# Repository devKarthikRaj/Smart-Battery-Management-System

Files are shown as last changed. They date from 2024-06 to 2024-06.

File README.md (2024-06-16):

# NTU EE3180 Design Innovation Project 3S Battery Management System (BMS) AY2023-24
> [!IMPORTANT]
> This was a group project. The parts of the project I worked on are in this repo.

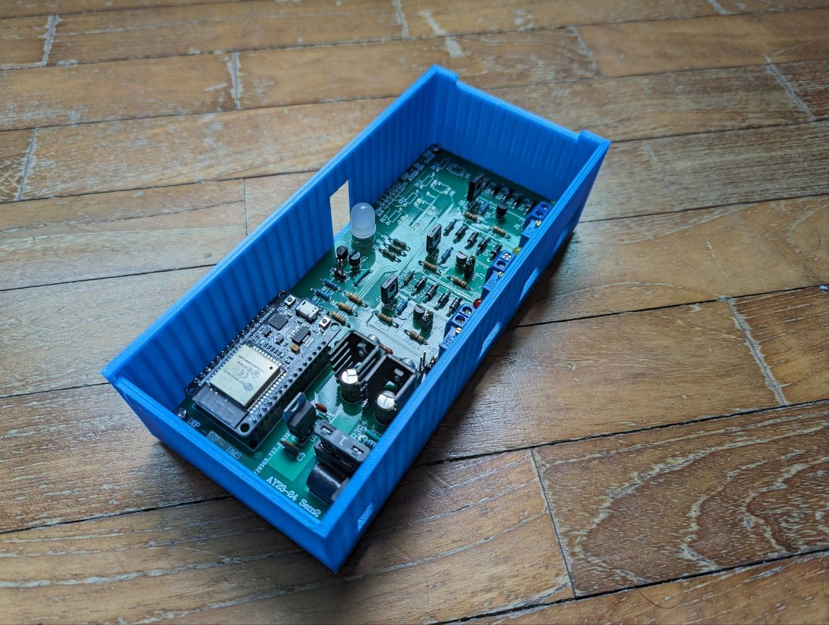
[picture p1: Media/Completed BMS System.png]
<br>

## About
With the advent of electric vehicles, charging has become an integral part of our daily lives. This has resulted in a sudden increase in the demand for battery chargers, specifically lithium-ion battery chargers. These lithium-ion batteries are very needy. They have to be charged at a specific voltage and current to remain healthy and function reliably. When charging multiple lithium-ion cells in a battery pack, they have to be charged and discharged in a balanced manner. Over-charging or over-discharging a particular cell in a battery pack could lead to dire consequences i.e the battery going BOOM!!! Now we certainly do not want that. This is where our battery management system (BMS) comes in. 

This BMS we created balance charges 3 lithium-ion cells, basically a glorified lithium-ion battery charger. Why glorified? Well, most chargers / passive BMS on the market right now just charge batteries. There is no monitoring capability whatsoever. Due to this, we cannot leave our batteries unattended while charging them. What if I want to do a grocery run while I charge my batteries? What if I want to go for an evening run while I charge my batteries? I can't do any of those things. This is where our BMS comes in! Our BMS lets you monitor your batteries while they are charging from anywhere in the world through a webpage and a mobile app available on both iOS and Android devices. 

## Contents
The parts of the project I worked on are the BMS PCB designed in Altium Designer, a part of the ESP32 firmware written in C++ through the Arduino IDE and an enclosure for the PCB designed in Fusion 360 and 3D printed with TPU.

## BMS PCB
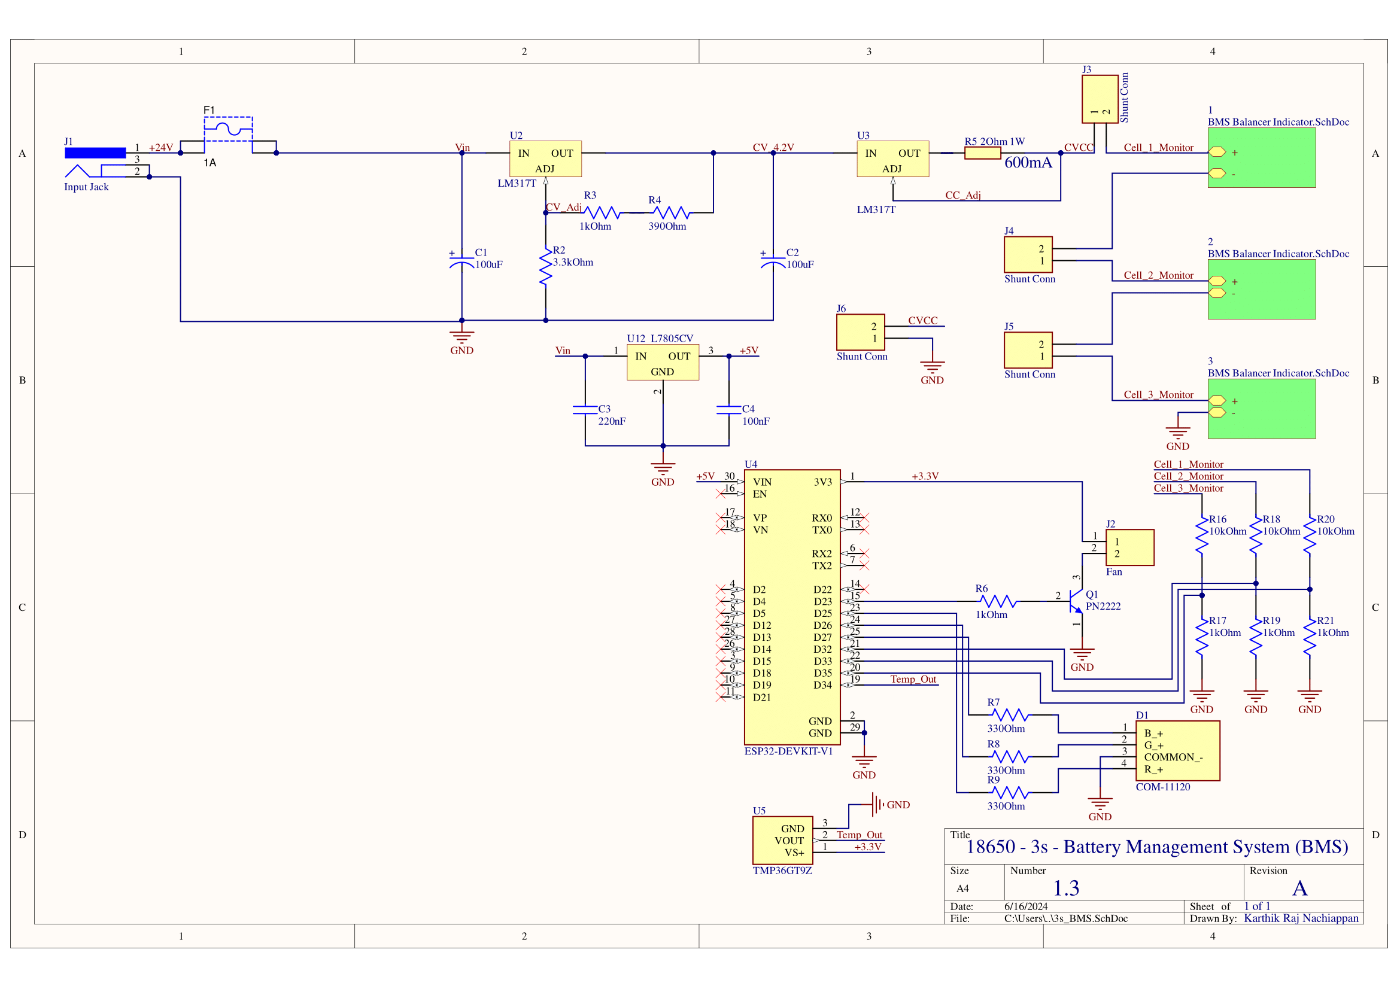
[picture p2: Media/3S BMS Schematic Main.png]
<br>
This is the main schematic. The top half of the schematic is the constant voltage constant current CV/CC circuit implemented using an adjustable LM317 voltage regulator. The bottom half of the schematic is the ESP32 microcontroller board to sensor/actuator interface circuit - This circuit connects the onboard temperature sensor, RGB LED and mini fan to the the microcontroller. This circuit also connects various parts of the charging circuit to the ESP32 to allow the microcontroller to non-invasively monitor the charging process.

&nbsp;

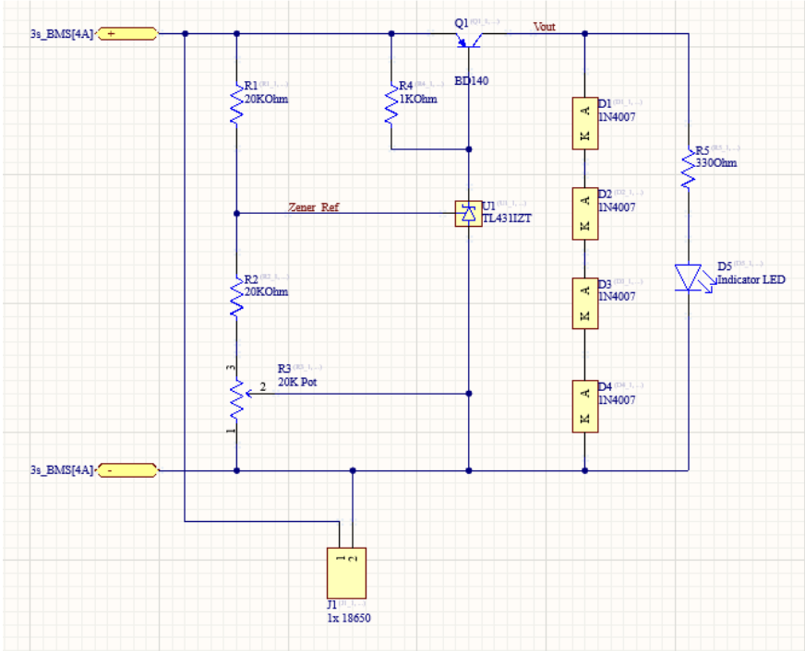
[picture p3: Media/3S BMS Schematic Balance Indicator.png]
<br>
This circuit is contained inside the green circuit blocks in the main schematic. This particular circuit is in charge of cutting off the charging process when the max desired cell voltage has been reached. This max desired cell voltage can be set by adjusting the potentiometer. Once the max desired cell voltage is reached, the indicator LED will light up giving a visual indicator to the user that the charging process is complete.

&nbsp;

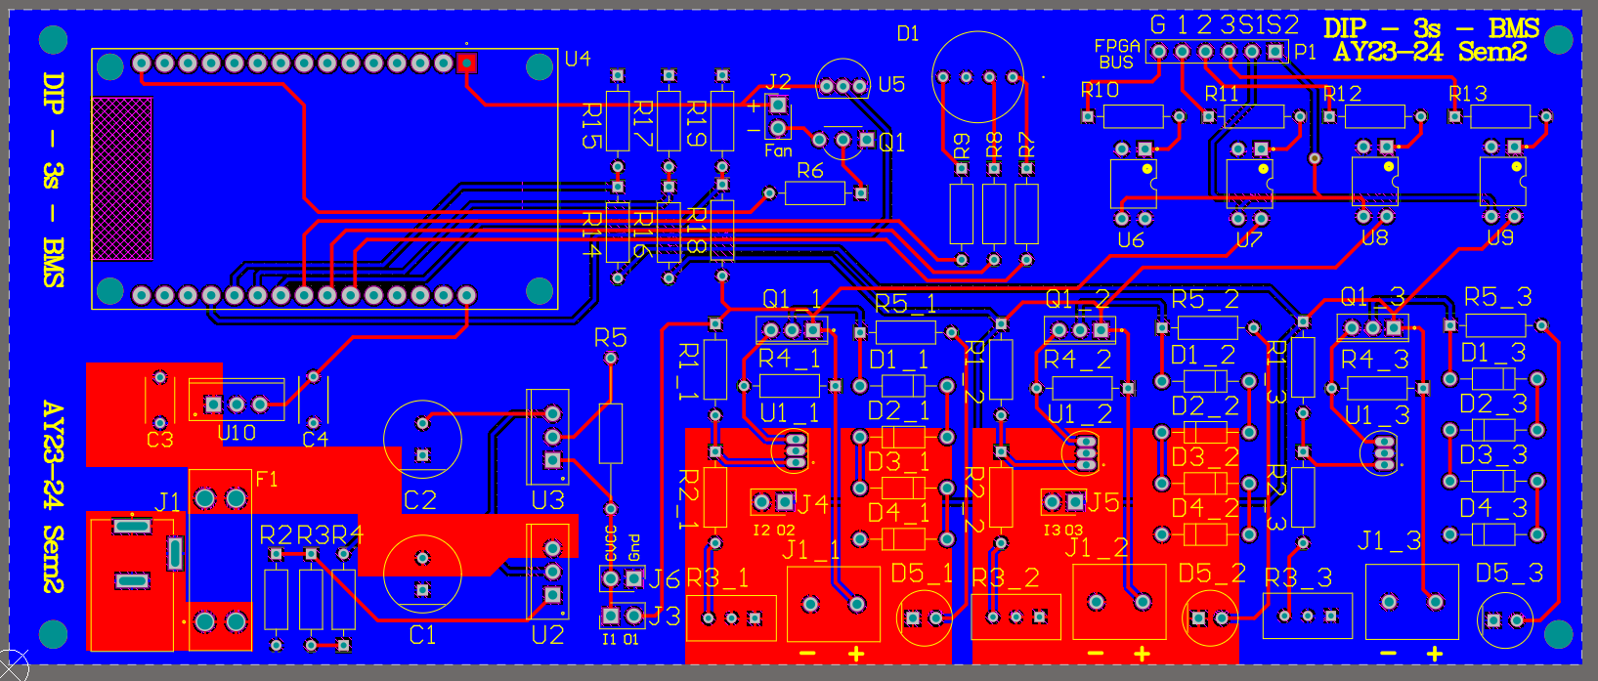
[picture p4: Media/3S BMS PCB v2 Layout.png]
<br>
This is the layout of the BMS PCB. Copper pours (polygons) have been used for power nets to keep this PCB as cool as a cucumber! <br>

&nbsp;

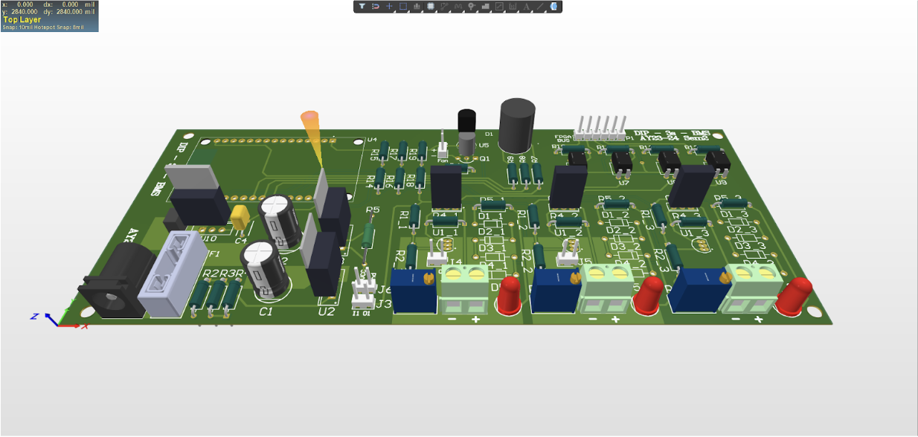
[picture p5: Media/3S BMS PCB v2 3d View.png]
<br>
Here's a 3D render of the PCB. Note that the ESP32 microcontroller board is not shown in the render.

### BMS PCB Features
●	Up to 3 lithium-ion batteries can be charged simultaneously with this PCB. <br>
●	DC Jack for input voltage from a wall plug. <br>
●	ATOF series blade fuse for overcurrent protection is easily replaceable by the user. <br>
●	3 Potentiometers enable the user to adjust the maximum charge voltage of each battery separately thereby allowing the user to charge various types of lithium-ion cells to different voltages as and when required. <br>
●	3 Single colour indicator LEDs to alert the user when each battery has been fully charged. <br>
●	RGB LED to indicate SoH and charging status. <br>
●	Temperature sensor to sense ambient temperature. <br>
●	Interface for a small ventilator fan to keep the PCB at desirable temperatures (~25°C-30°C). <br>
●	Onboard microcontroller with WiFi capabilities to monitor all parameters of the BMS. <br>
●	A detailed breakdown of all parameters (3 cell voltages, SoC, SoH and ambient temperature) and trend charts available through a web interface (ThingSpeak).
●	3 Cell voltages and ambient temperature also available through a mobile application on both iOS and Android devices.

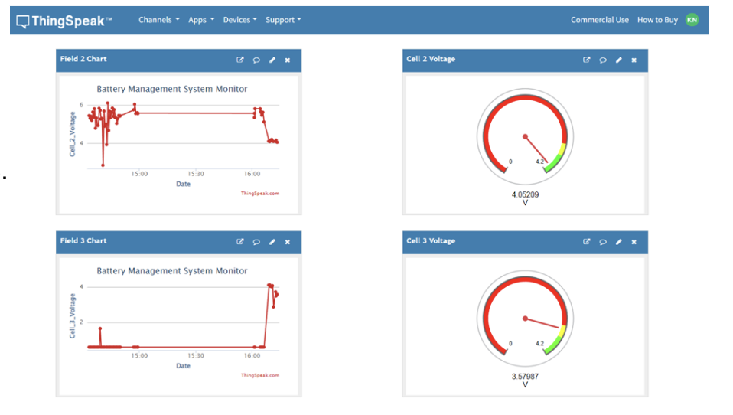
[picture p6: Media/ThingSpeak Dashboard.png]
<br><br>

## BMS Enclosure CAD Model
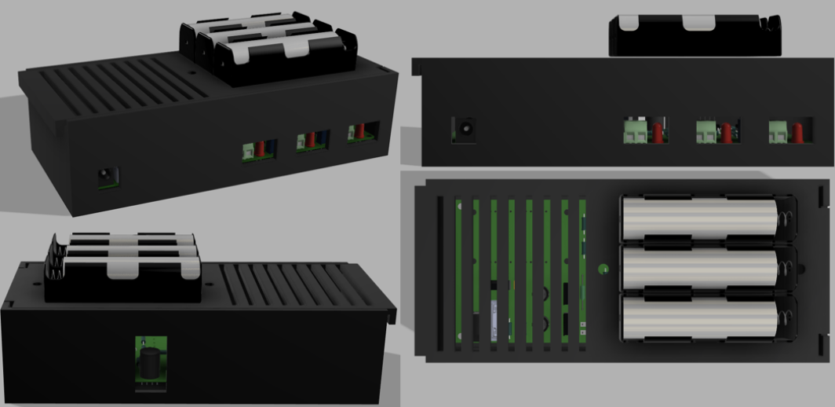
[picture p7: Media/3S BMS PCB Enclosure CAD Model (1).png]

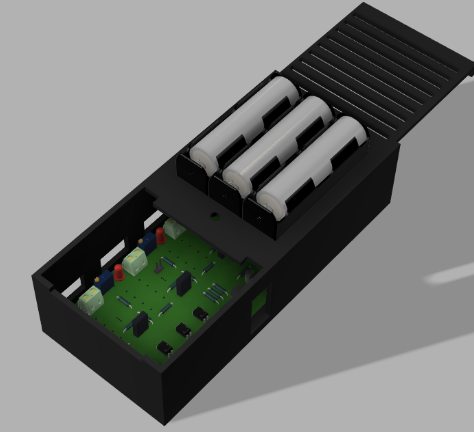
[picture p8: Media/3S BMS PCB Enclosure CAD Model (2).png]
<br>
Here is a 3D render of the BMS Enclosure. This model was 3D printed in TPU. The mini ventilator fan is not shown in this render.

# Conclusion
Many aspects of this project could be improved. A more modern PMIC could have been used as compared to the LM317 - a veteran, tried and tested PMIC in my opinion. An ESP32 micrcontroller circuit could have directly been implemented on the BMS PCB itself instead of using a pluggable module (development board). SoC could have been implemented using columb counting using a current sensor like the INA219. The cut off voltage could have been dynamically adjusted by the ESP32 based on the SoH of the battery. However this was just a prototype. This project was designed and realized in the span of 13 weeks.

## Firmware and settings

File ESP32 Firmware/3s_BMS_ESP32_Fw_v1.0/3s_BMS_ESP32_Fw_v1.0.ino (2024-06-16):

//Constant Definitions
#define ambientTempThreshold 15  //Fan will turn on if temp exceeds 30 deg C
#define BLYNK_PRINT Serial
#define BLYNK_TEMPLATE_ID "TMPL6m-UOY92p" // Access code for Blynk
#define BLYNK_TEMPLATE_NAME "BMS" // Access code for Blynk
#define BLYNK_AUTH_TOKEN "M9BpsXbl3JkOrzozAKsXzokN0JTHX8Of"// Access code for Blynk
#define V1 1
#define V2 2
#define V3 3
#define V4 4

// Blynk Auth Token
char auth[] = BLYNK_AUTH_TOKEN;

//Pin Definitions
const int cell1Pin      =  33;  //Cell 1 voltage pin
const int cell2Pin      =  32;  //Cell 2 voltage pin
const int cell3Pin      =  35;  //Cell 3 voltage pin
const int tempSensePin  =  34;  //Temperature sensor pin
const int fanConPin     =  23;  //Fan control pin
const int rPin          =  25;  //RGB red pin
const int gPin          =  26;  //RGB green pin
const int bPin          =  27;  //RGB blue pin

//Add Libraries
#include <WiFi.h>
#include <ThingSpeak.h>
#include <BlynkSimpleEsp32.h>

//WiFi Vars
const char* ssid = "";    // ***Remove before pushing***
const char* pwd = "";     //***Remove before pushing***
WiFiClient client;

//Charge Stats Vars
unsigned long cell1EndChargeTime;
unsigned long cell2EndChargeTime;
unsigned long cell3EndChargeTime;
bool cell1EndChargeTimerFlag = false;
bool cell2EndChargeTimerFlag = false;
bool cell3EndChargeTimerFlag = false;
float lastUpdatedVc1;
float lastUpdatedVc2;
float lastUpdatedVc3;

void setup() {
  Serial.begin(115200); //Init serial

  ConnectWifi(); //This is a blocking function!!!

  ThingSpeak.begin(client); //Initialize ThingSpeak
  Blynk.begin(auth, ssid, pwd); // Initialize Blynk

  //IO Definitions
  pinMode(cell1Pin, INPUT);
  pinMode(cell2Pin, INPUT);
  pinMode(cell3Pin, INPUT);
  pinMode(tempSensePin, INPUT);
  pinMode(fanConPin, OUTPUT);
  pinMode(rPin, OUTPUT);
  pinMode(gPin, OUTPUT);
  pinMode(bPin, OUTPUT);

  DriveRgb(0,0,0); //Initially set RGB led to off
}

void loop() {
  ConnectWifi();  //ConnectWifi called again in case Wifi abruptly disconnects

  Blynk.run(); // Run Blynk loop

  //Read stepped down added cell voltages and calculate the actual added cell voltages
  float Vc1 = CellVoltageSense(cell1Pin); //+ 1.130; //Offset for res tolerance
  float Vc2 = CellVoltageSense(cell2Pin); //+ 1.100; //Offset for res tolerance
  float Vc3 = CellVoltageSense(cell3Pin); //+ 2.590; //Offset for res tolerance

  //Calculate individual cell voltages
  Vc1 = Vc1 - Vc2;
  Vc2 = Vc2 - Vc3 - 0.15;
  Vc3 = Vc3 + 2.49;
  //Vc3 is the actual voltage of the 3rd cell

  //Calculate SOC
  float cell1SOC = calculateSOC(Vc1);
  float cell2SOC = calculateSOC(Vc2);
  float cell3SOC = calculateSOC(Vc3);
  
  //Set SOH to -1 to indicate that SOH cannot be calculated as battery is not fully charged
  float cell1SOH = -1;
  float cell2SOH = -1;
  float cell3SOH = -1;
  float combinedSOH = -1;
  
  if (Vc1 > 4.1) { // Good battery
    if (cell1EndChargeTimerFlag) {
      cell1EndChargeTime = millis();
      DriveRgb(0, 255, 0);  // Blink green 1 time
      cell1EndChargeTimerFlag = false;
    }
    // Calculate SOH only when battery is at full charge
    float cell1SOH = calculateSOH(Vc1);
  } else { // Bad battery
    if (lastUpdatedVc1 == Vc1 && !timerStarted) {
      unsigned long currentTime = millis();
      if (currentTime - cell1EndChargeTime >= 180000) {  // Check if 3 minutes has passed
        //timerStarted = true;  // Start the timer
        DriveRgb(0, 255, 0);  // Flash green
        delay(50);  // Adjust delay time as needed
        DriveRgb(0, 0, 0);  // Turn off LED
        delay(50);  // Adjust delay time as needed
      }
    }
  }
  lastUpdatedVc1 = Vc1;  // Update last updated Vc1 value
  
  if (Vc2 > 4.1) { // Good battery
    if (cell2EndChargeTimerFlag) {
      cell2EndChargeTime = millis();
      DriveRgb(255, 255, 0);  // Blink yellow 1 time
      cell2EndChargeTimerFlag = false;
    }
    // Calculate SOH only when battery is at full charge
    float cell2SOH = calculateSOH(Vc2);
  } else { // Bad battery
    if (lastUpdatedVc2 == Vc2 && !timerStarted) {
      unsigned long currentTime = millis();
      if (currentTime - cell2EndChargeTime >= 180000) {  // Check if 3 minutes has passed
        //timerStarted = true;  // Start the timer
        DriveRgb(255, 255, 0);  // Flash yellow
        delay(50);  // Adjust delay time as needed
        DriveRgb(0, 0, 0);  // Turn off LED
        delay(50);  // Adjust delay time as needed
      }
    }
  }
  lastUpdatedVc2 = Vc2;  // Update last updated Vc2 value


  if (Vc3 > 4.1) { // Good battery
    if (cell3EndChargeTimerFlag) {
      cell3EndChargeTime = millis();
      DriveRgb(255, 0, 0);  // Blink red 1 time
      cell3EndChargeTimerFlag = false;
    }
    // Calculate SOH only when battery is at full charge
    float cell3SOH = calculateSOH(Vc3);
  } else { // Bad battery
    if (lastUpdatedVc3 == Vc3 && !timerStarted) {
      unsigned long currentTime = millis();
      if (currentTime - cell3EndChargeTime >= 180000) {  // Check if 3 minutes has passed
        //timerStarted = true;  // Start the timer
        DriveRgb(255, 0, 0);  // Flash red
        delay(100);  // Adjust delay time as needed
        DriveRgb(0, 0, 0);  // Turn off LED
        delay(100);  // Adjust delay time as needed
      }
    }
  }
  lastUpdatedVc3 = Vc3;  // Update last updated Vc2 value

  combinedSOH = ((cell1SOH+cell2SOH+cell3SOH) / 300) * 100;
  
  //Read Ambient Temp + Fan Control
  float ambientTemp = TempSense(34);
  
  if (ambientTemp > ambientTempThreshold) {
    digitalWrite(fanConPin, HIGH);
  }

  //Publish all cell monitoring data to Blynk
  PublishBlynkData(Vc1,Vc2,Vc3,ambientTemp);
  
  //Publish all cell monitoring data to ThingSpeak
  ThingSpeakWrite8Floats(Vc1, Vc2, Vc3, cell1SOC, cell2SOC, cell3SOC, combinedSOH, ambientTemp);
}

void ConnectWifi() {
  if (WiFi.status() != WL_CONNECTED) {
    Serial.print("Connecting to Wifi");
    while (WiFi.status() != WL_CONNECTED) {
      WiFi.begin(ssid, pwd);
      Serial.print(".");
      delay(5000);  //Removing this delay will cause the ESP32 to crash while connecting to a wifi network
    }
    Serial.println("\nConnected to Wifi");
  }
}

//Reads the raw stepped down added cell voltage and converts this raw reading back to the actual added cell voltage
float CellVoltageSense(int cellVoltageSensePin) {
  //Conversion Vars
  const float conversionFactor = 3.3 / 4096;  //Li ion max cell voltage = 4.2 and ESP32 ADC = 12 bits so 2^12 = 4096
  const float conversionOffset = -0.1;        //ADC conversion offset
  const int Rb = 10;
  const int Rs = 1;

  int cellVoltageRaw = analogRead(cellVoltageSensePin);
  
  //Conversion
  float Vs = (cellVoltageRaw * conversionFactor) + conversionOffset; //Calculate raw voltage from ADC value
  float Vb = ((Rs+Rb)/Rs) * Vs; //Calculate actual added cell voltage (Vb = Vbig)

  //Debugging
  //Serial.println();
  //Serial.print("Cell Voltage Raw: ");
  //Serial.print(cellVoltageRaw);
  //Serial.print(" Cell Voltage Actual: ");
  ///Serial.print(Vb);
  //Serial.println();

  return Vb;
}

void PublishBlynkData(float data1, float data2, float data3, float data4) {
  // Send data to Blynk
  Blynk.virtualWrite(V1, data1);
  Blynk.virtualWrite(V2, data2);
  Blynk.virtualWrite(V3, data3);
  Blynk.virtualWrite(V4, data4);
  delay (1000);
}

bool ThingSpeakWrite8Floats(float data1, float data2, float data3, float data4, float data5, float data6, float data7, float data8) {
  //ThingSpeak Vars
  unsigned long channelId = 2454172;            //***Remove before pushing***
  const char* writeAPIKey = "4POHYZ95Y3YP52OG"; //***Remove before pushing***
  int writeStatus = false;

  ThingSpeak.setField(1, data1);
  ThingSpeak.setField(2, data2);
  ThingSpeak.setField(3, data3);
  ThingSpeak.setField(4, data4);
  ThingSpeak.setField(5, data5);
  ThingSpeak.setField(6, data6);
  ThingSpeak.setField(7, data7);
  ThingSpeak.setField(8, data8);
  int writeStatusCode = ThingSpeak.writeFields(channelId, writeAPIKey);

  //Debugging
  /*//ThingSpeak will return HTTP status code 200 if successful
  if (writeStatusCode == 200) {
    Serial.println("ThingSpeak Channel update successful.");
    return true;
  } else {
    Serial.println("Problem updating ThingSpeak channel... HTTP error code " + String(writeStatusCode));
    return false;
  }*/

  //If the data packets are sent out in under 15s intervals, HTTP status code 401 will be returned
  //Some packets will still be sent but this is not recommended
  //So set min delay to atleast 15s
  
  //Blink RGB led to indicate looping
  DriveRgb(255,50,0);
  delay(300);
  DriveRgb(0,0,0);
  delay(300);
  delay(5000);
  
  DriveRgb(255,50,0);
  delay(300);
  DriveRgb(0,0,0);
  delay(300);
  delay(5000);

  DriveRgb(255,50,0);
  delay(300);
  DriveRgb(0,0,0);
  delay(300);
  delay(5000);

  DriveRgb(255,50,0);
  delay(300);
  DriveRgb(0,0,0);
  delay(300);
  delay(5000);
}

float TempSense(int tempSensePin) {
  //Conversion Vars
  const float conversionFactor = 3.3 / 4096;  //System max voltage = 3.3V as ESP ADC runs on 3.3V and ESP32 ADC = 12 bits so 2^12 = 4096
  const float conversionOffset = 0.1;           //ADC conversion offset

  //Conversion
  int tempRaw = analogRead(tempSensePin);
  float temp = (((tempRaw * conversionFactor) + conversionOffset) - 0.5) * 100;

  return temp;
}

float calculateSOC(float voltage) {
  //Define voltage range and corresponding SOC values
  float minVoltage = 3.2;  //Minimum bat voltage
  float maxVoltage = 4.2;  //Maximum bat voltage
  float minSOC = 0.0;      //Minimum SOC when bat is empty
  float maxSOC = 100.0;    //Maximum SOC when bat is on full charged

  //Calculate SOC with linear interpolation formula
  float soc = ((voltage - minVoltage) / (maxVoltage - minVoltage)) * 100;

  // Ensure SOC stays within valid range
  soc = max(minSOC, min(maxSOC, soc));

  return soc;
}

float calculateSOH(float voltage) {
  // Initial fully charged voltage (for example)
  float initialVoltage = 4.2;

  // Calculate SOH as a percentage of initial voltage
  float soh = (voltage / initialVoltage) * 100.0;

  // Ensure SOH stays within valid range
  soh = max(0.0f, min(100.0f, soh)); // It returns the larger of the 2 values, this is used to keep it within the range

  return soh;
}

void DriveRgb(int redvalue, int greenvalue, int bluevalue) {
  analogWrite(rPin, redvalue);
  analogWrite(gPin, greenvalue);
  analogWrite(bPin, bluevalue);
}

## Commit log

2024-03-03 This code can publish to thingspeak with errors
    [3s_BMS_ESP32_Fw_v1.0.ino]
2024-04-07 All functions done except RGB led (Edit for ZH)
2024-06-16 Added PCB files and media and updated readme
2024-06-16 Unzipped PCB folder
    [3s_BMS.PcbDoc, 3s_BMS.SchDoc, BMS Balancer Indicator.SchDoc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]
